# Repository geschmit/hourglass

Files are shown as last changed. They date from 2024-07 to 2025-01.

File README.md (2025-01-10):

# Hourglass
Hourglass is a custom PCB watch designed in KiCAD 7.0, to be funded by the Hack Club [OnBoard](https://github.com/hackclub/OnBoard/) grant, which allocates $100 for high schoolers to design and build their own custom PCBs.

## Features
- Accelerometer & Magnetometer for detecting orientation and movement
- 60 individual LEDs for displaying minutes & seconds
- RTC for high-precision timekeeping
- Programmable user buttons
- Revision A:
  - FIDO2 Authentication token
  - USB-C interface
- Revision B:
  - Cheap manufacturing cost

## Revisions
### [Revision A:](./hourglass_reva/) Working design iteration
> `Status: ✔️ (COMPLETE)`
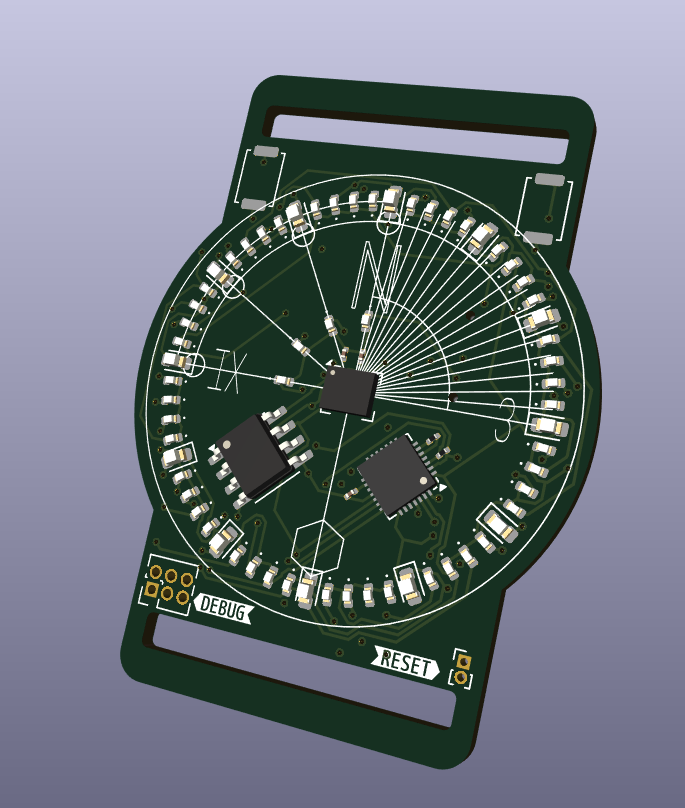
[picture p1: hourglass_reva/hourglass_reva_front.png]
reva front

Revision A is the original design, based on the Atmel ATMega32u4 microcontroller. It features a RTC and 9DoF magnetometer-accelerometer to detect orientation, magnetic field strength and more to act as both a device for keeping time and sense when the wearer has raised the watchface to observe. In addition, a USB-C port can allow for interfacing directly to the Mega for uploading code and other functions.

### [Revision B:](./hourglass_revb/) Cost-effective design
> `Status: ✔️ (COMPLETE)`
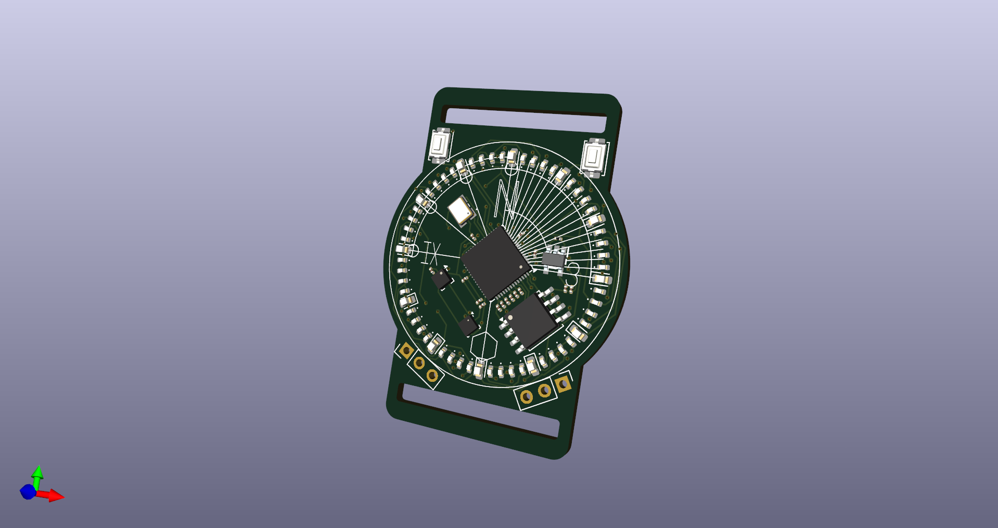
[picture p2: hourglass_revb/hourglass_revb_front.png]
revb front

Revision B is a easier, more affordable option. I'm working on this primarily because revision A is simply too expensive with all peripherals added in to have assembled via JLC's PCBA. It swaps the ATMega32 with an RP2040, the 9DoF magnetometer with split magnetometer & accelerometer ICs, and forgoes the rear battery slot alltogether. The caveat with this is you'll need to wire a battery to the device yourself, but comes at a tremendous discount with the requirement for dual-sided PCB assembly forgone.

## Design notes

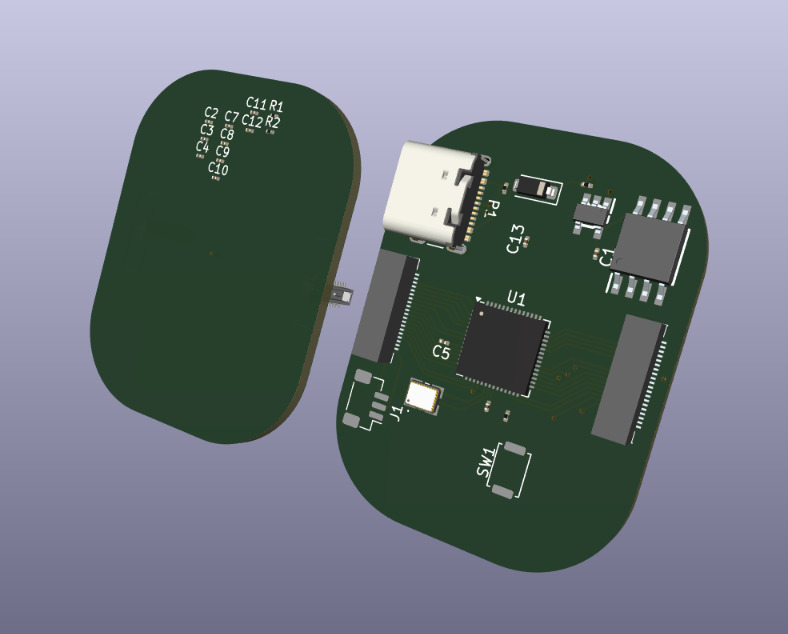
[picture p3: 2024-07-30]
hourglass_prototype/hourglass_prototype_front.png

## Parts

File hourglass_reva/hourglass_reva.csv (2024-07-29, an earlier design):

Id | Designator | Footprint | Quantity | Designation | Supplier and ref
1 | U1 | QFN-44-1EP_7x7mm_P0.5mm_EP5.2x5.2mm | 1 | ATmega32U4-M
2 | U2 | QFN-28-1EP_4x4mm_P0.4mm_EP2.3x2.3mm | 1 | IS31FL3731-QF

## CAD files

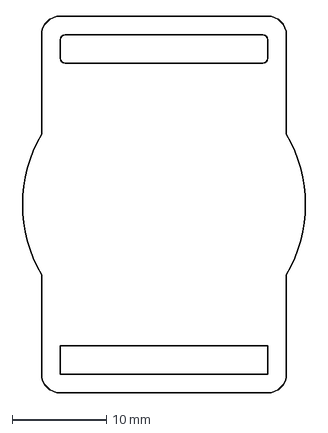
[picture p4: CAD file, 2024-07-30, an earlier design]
hourglass_reva/hourglass_base.dxf
31.3 x 40.0 mm

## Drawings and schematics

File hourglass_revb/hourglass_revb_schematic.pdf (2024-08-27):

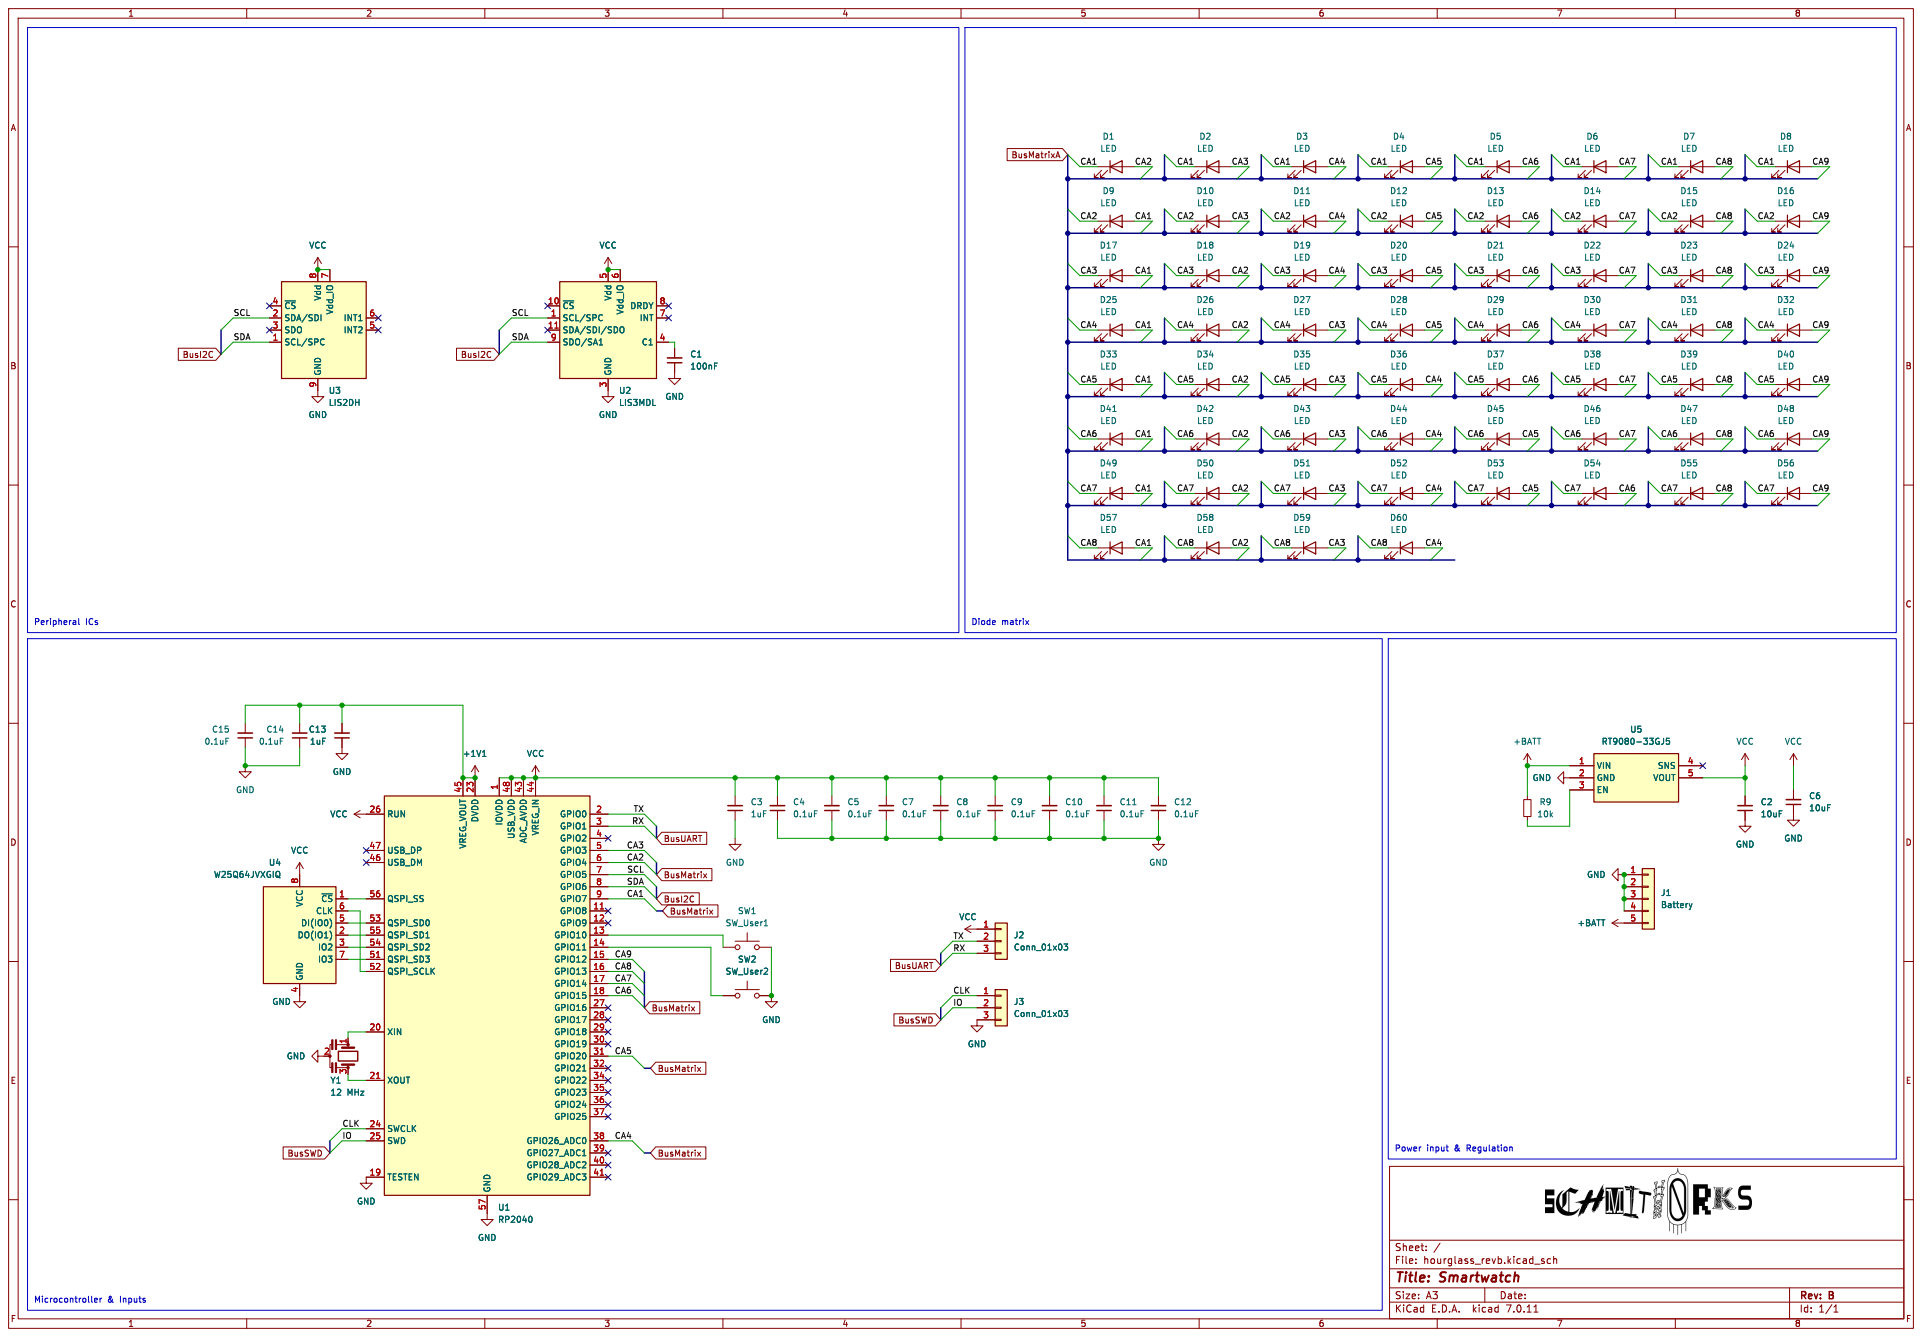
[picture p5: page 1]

SCL/SPC 1 SDA/SDI 2 SDO 3 ~{CS} 4

1 GPIO8 11 GPIO9 12 GPIO10 13 GPIO11 14 GPIO12 15 GPIO13 16 GPIO14 17 GPIO15 18 TESTEN 19 GPIO0 2 XIN 20 XOUT 21 DVDD 23 SWCLK 24 SWD 25 RUN 26 GPIO16 27 GPIO17 28 GPIO18 29 GPIO1 3 GPIO19 30 GPIO20 31 GPIO21 32 GPIO22 34 GPIO23 35 GPIO24 36 GPIO25 37 GPIO26_ADC0 38 GPIO27_ADC1 39 GPIO2 4 GPIO28_ADC2 40 GPIO29_ADC3 41 ADC_AVDD 43 VREG_IN 44 VREG_VOUT 45 USB_DM 46 USB_DP 47 USB_VDD 48 GPIO3 5 QSPI_SD3 51 QSPI_SCLK 52 QSPI_SD0 53 QSPI_SD2 54 QSPI_SD1 55 QSPI_SS 56 GND 57 GPIO4 6 GPIO5 7 GPIO6 8 GPIO7 9 VCC

1 GPIO8 11 GPIO9 12 GPIO10 13 GPIO11 14 GPIO12 15 GPIO13 16 GPIO14 17 GPIO15 18 TESTEN 19 GPIO0 2 XIN 20 XOUT 21 DVDD 23 SWCLK 24 SWD 25 RUN 26 GPIO16 27 GPIO17 28 GPIO18 29 GPIO1 3 GPIO19 30 GPIO20 31 GPIO21 32 GPIO22 34 GPIO23 35 GPIO24 36 GPIO25 37 GPIO26_ADC0 38 GPIO27_ADC1 39 GPIO2 4 GPIO28_ADC2 40 GPIO29_ADC3 41 ADC_AVDD 43 VREG_IN 44 VREG_VOUT 45 USB_DM 46 USB_DP 47 USB_VDD 48 GPIO3 5 QSPI_SD3 51 QSPI_SCLK 52 QSPI_SD0 53 QSPI_SD2 54 QSPI_SD1 55 QSPI_SS 56 GND 57 GPIO4 6 GPIO5 7 GPIO6 8 GPIO7 9 U1 RP2040 ~{CS}1 DO(IO1) 2

3 GND GND GND GND

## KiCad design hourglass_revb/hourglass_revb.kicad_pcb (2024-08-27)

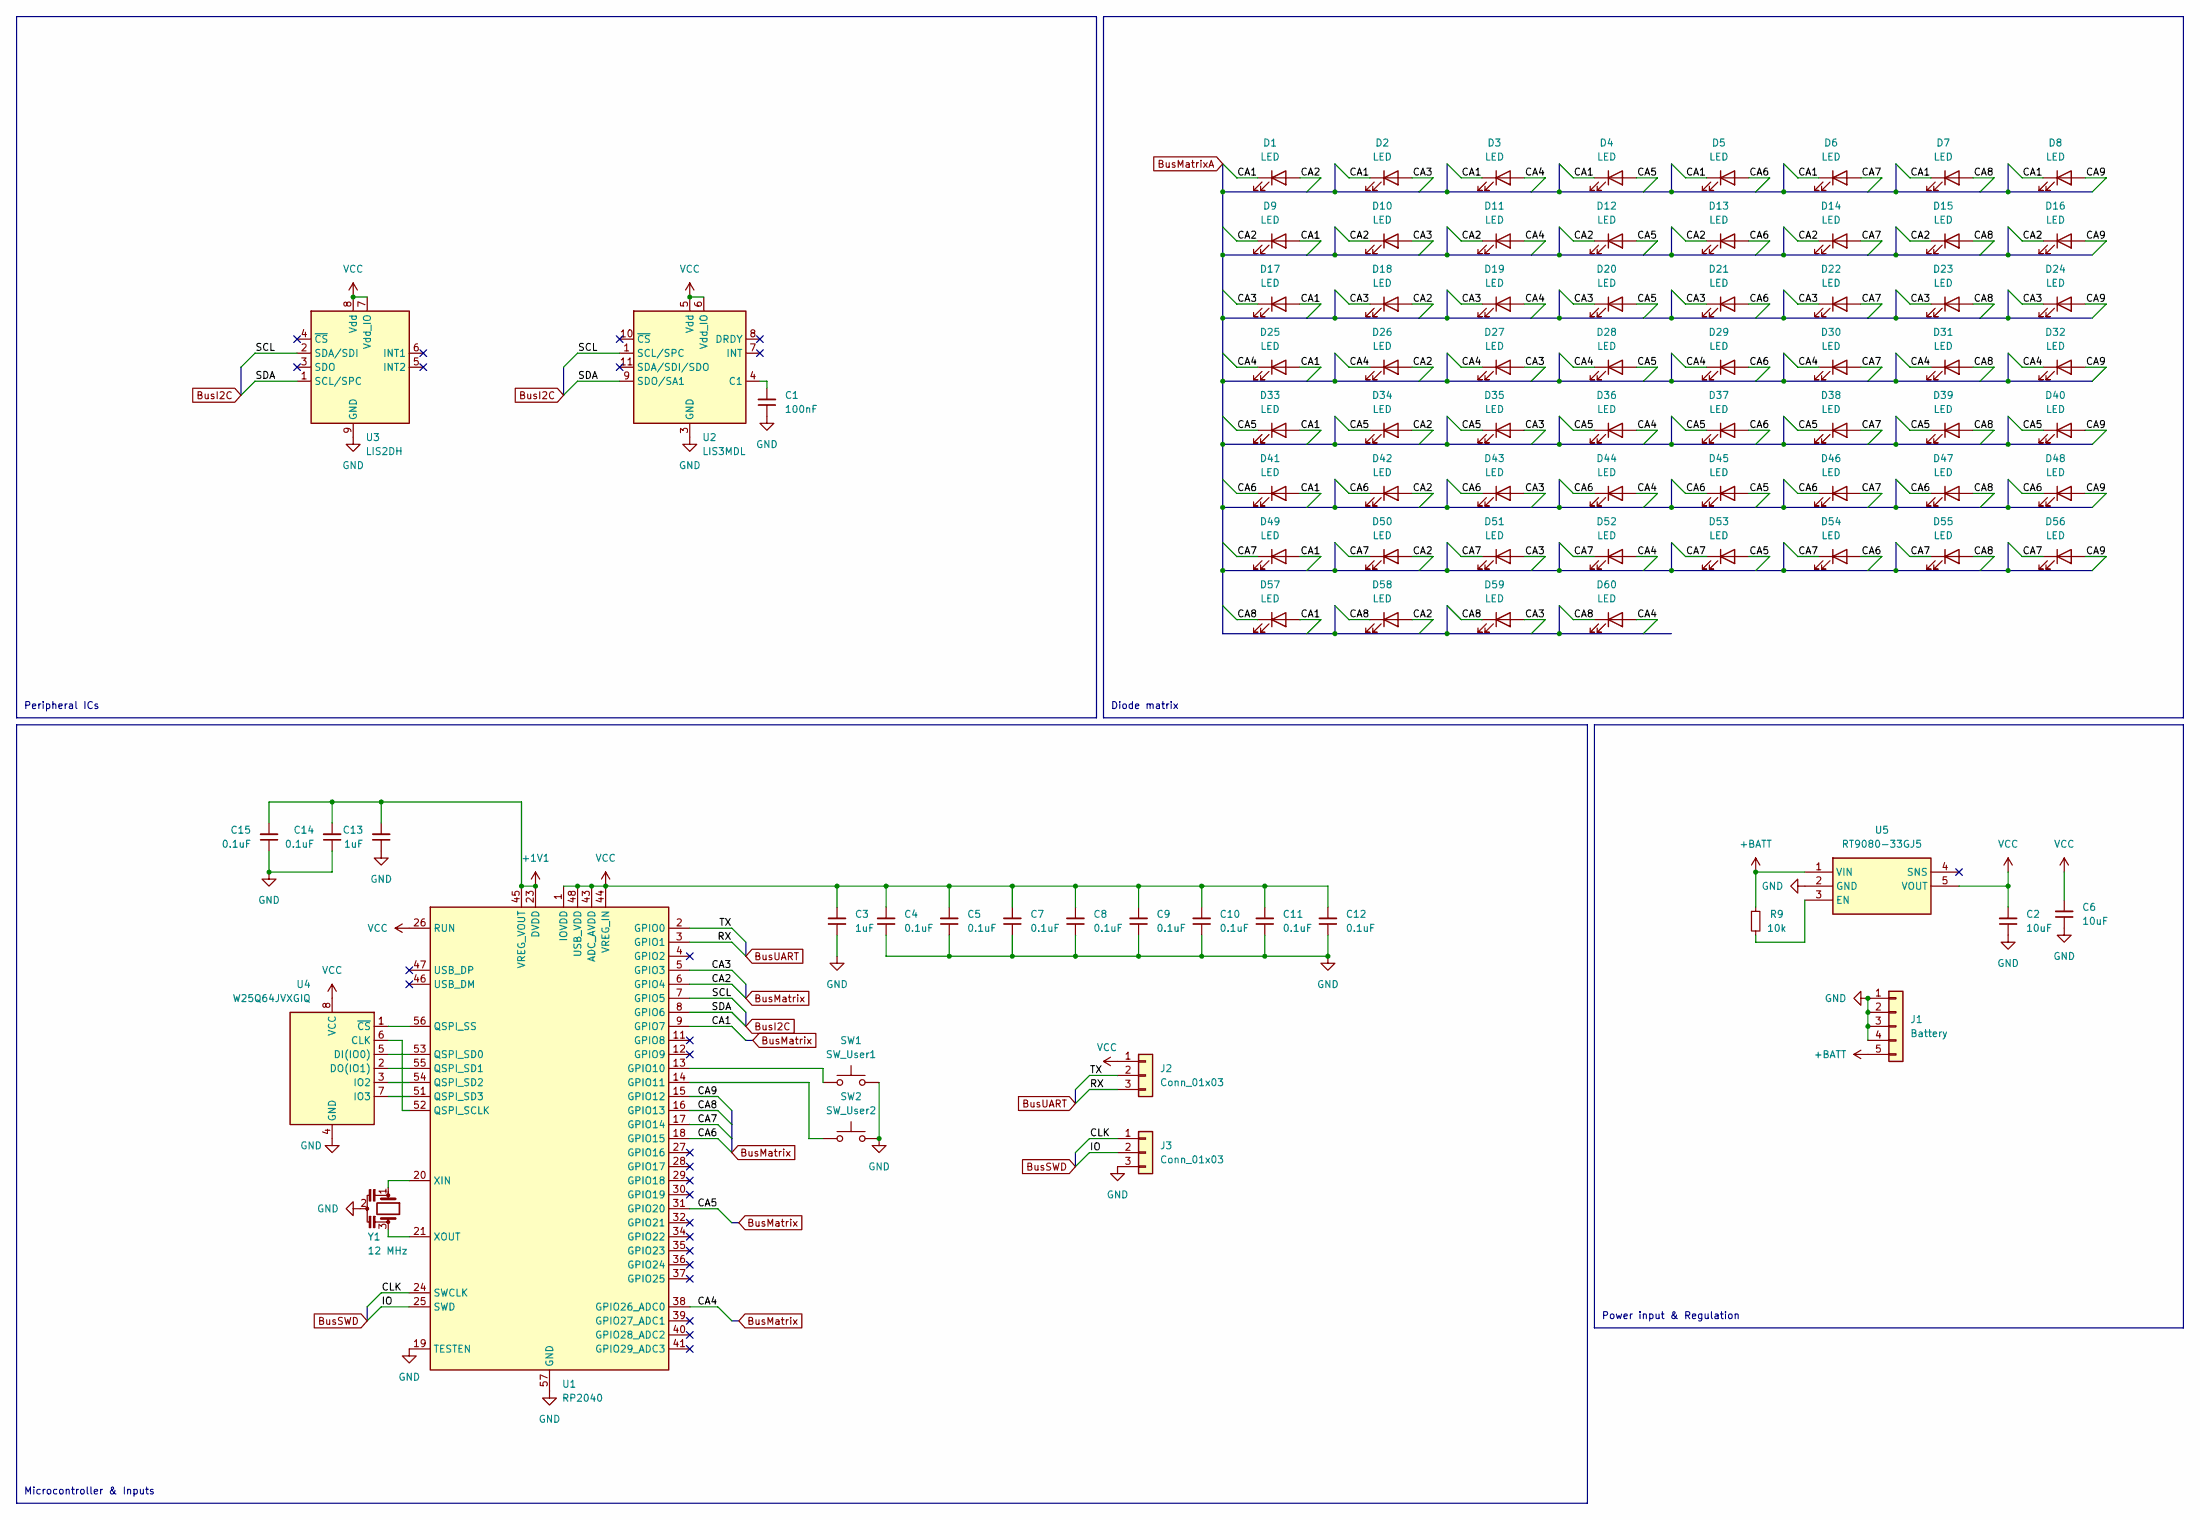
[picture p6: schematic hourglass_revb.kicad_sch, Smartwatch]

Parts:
C1: 100nF; C_0201_0603Metric
C2, C6: 10uF; C_0201_0603Metric
C3, C13: 1uF; C_0201_0603Metric
C4, C5, C7, C8, C9, C10, C11, C12, C14, C15: 0.1uF; C_0201_0603Metric
D1, D6, D11, D16, D21, D26, D31, D36, D41, D46, D51, D56: LED; LED_0603_1608Metric
D2, D3, D4, D5, D7, D8, D9, D10, D12, D13, D14, D15, D17, D18, D19, D20, D22, D23, D24, D25, D27, D28, D29, D30, D32, D33, D34, D35, D37, D38, D39, D40, D42, D43, D44, D45, D47, D48, D49, D50, D52, D53, D54, D55, D57, D58, D59, D60: LED; LED_0402_1005Metric
J1: Battery; BAT_BAT-HLD-001-THM
J2, J3: Conn_01x03; PinHeader_1x03_P2.54mm_Vertical
R9: 10k; R_0201_0603Metric
SW1: SW_User1; SW_Push_SPST_NO_Alps_SKRK
SW2: SW_User2; SW_Push_SPST_NO_Alps_SKRK
U1: RP2040; QFN-56-1EP_7x7mm_P0.4mm_EP3.2x3.2mm
U2: LIS3MDL; LGA-12_2x2mm_P0.5mm
U3: LIS2DH; LGA-14_2x2mm_P0.35mm_LayoutBorder3x4y
U4: W25Q64JVXGIQ; WSON-8-1EP_6x5mm_P1.27mm_EP3.4x4.3mm
U5: RT9080-33GJ5; SOT94P280X100-5N; Manufacturer_Part_Number RT9080-33GJ5; Mouser Part Number 835-RT9080-33GJ5
Y1: 12 MHz; ABM8272T3

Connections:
+1V1: C13.2, C14.2, C15.2, U1.23 (DVDD), U1.45 (VREG_VOUT), U1.50 (DVDD)
+BATT: J1.5, R9.1, U5.1 (VIN)
/CA1: D1.1 (K), D2.1 (K), D3.1 (K), D4.1 (K), D5.1 (K), D6.1 (K), D7.1 (K), D8.1 (K), D9.2 (A), D17.2 (A), D25.2 (A), D33.2 (A), D41.2 (A), D49.2 (A), D57.2 (A), U1.9 (GPIO7)
/CA2: D1.2 (A), D9.1 (K), D10.1 (K), D11.1 (K), D12.1 (K), D13.1 (K), D14.1 (K), D15.1 (K), D16.1 (K), D18.2 (A), D26.2 (A), D34.2 (A), D42.2 (A), D50.2 (A), D58.2 (A), U1.6 (GPIO4)
/CA3: D2.2 (A), D10.2 (A), D17.1 (K), D18.1 (K), D19.1 (K), D20.1 (K), D21.1 (K), D22.1 (K), D23.1 (K), D24.1 (K), D27.2 (A), D35.2 (A), D43.2 (A), D51.2 (A), D59.2 (A), U1.5 (GPIO3)
/CA4: D3.2 (A), D11.2 (A), D19.2 (A), D25.1 (K), D26.1 (K), D27.1 (K), D28.1 (K), D29.1 (K), D30.1 (K), D31.1 (K), D32.1 (K), D36.2 (A), D44.2 (A), D52.2 (A), D60.2 (A), U1.38 (GPIO26_ADC0)
/CA5: D4.2 (A), D12.2 (A), D20.2 (A), D28.2 (A), D33.1 (K), D34.1 (K), D35.1 (K), D36.1 (K), D37.1 (K), D38.1 (K), D39.1 (K), D40.1 (K), D45.2 (A), D53.2 (A), U1.31 (GPIO20)
/CA6: D5.2 (A), D13.2 (A), D21.2 (A), D29.2 (A), D37.2 (A), D41.1 (K), D42.1 (K), D43.1 (K), D44.1 (K), D45.1 (K), D46.1 (K), D47.1 (K), D48.1 (K), D54.2 (A), U1.18 (GPIO15)
/CA7: D6.2 (A), D14.2 (A), D22.2 (A), D30.2 (A), D38.2 (A), D46.2 (A), D49.1 (K), D50.1 (K), D51.1 (K), D52.1 (K), D53.1 (K), D54.1 (K), D55.1 (K), D56.1 (K), U1.17 (GPIO14)
/CA8: D7.2 (A), D15.2 (A), D23.2 (A), D31.2 (A), D39.2 (A), D47.2 (A), D55.2 (A), D57.1 (K), D58.1 (K), D59.1 (K), D60.1 (K), U1.16 (GPIO13)
/CA9: D8.2 (A), D16.2 (A), D24.2 (A), D32.2 (A), D40.2 (A), D48.2 (A), D56.2 (A), U1.15 (GPIO12)
/CLK: J3.1, U1.24 (SWCLK)
/IO: J3.2, U1.25 (SWD)
/RX: J2.3, U1.3 (GPIO1)
/SCL: U1.7 (GPIO5), U2.1 (SCL/SPC), U3.2 (SDA/SDI)
/SDA: U1.8 (GPIO6), U2.9 (SDO/SA1), U3.1 (SCL/SPC)
/TX: J2.2, U1.2 (GPIO0)
GND: C1.1, C2.1, C3.1, C4.1, C5.1, C6.1, C7.1, C8.1, C9.1, C10.1, C11.1, C12.1, C13.1, C14.1, C15.1, J1.1, J1.2, J1.3, J1.4, J3.3, SW1.2, SW2.2, U1.19 (TESTEN), U1.57 (GND), U2.2 (GND), U2.3 (GND), U2.12 (GND), U3.9 (GND), U3.10 (GND), U3.11 (GND), U3.12 (GND), U3.13 (GND), U3.14 (GND), U4.4 (GND), U5.2 (GND), Y1.2
unnamed: SW1.1, U1.13 (GPIO10)
unnamed: SW2.1, U1.14 (GPIO11)
unnamed: U1.52 (QSPI_SCLK), U4.6 (CLK)
unnamed: U1.53 (QSPI_SD0), U4.5 (DI(IO0))
unnamed: U1.55 (QSPI_SD1), U4.2 (DO(IO1))
unnamed: U1.54 (QSPI_SD2), U4.3 (IO2)
unnamed: U1.51 (QSPI_SD3), U4.7 (IO3)
unnamed: U1.56 (QSPI_SS), U4.1 (~CS)
unnamed: U1.20 (XIN), Y1.1
unnamed: U1.21 (XOUT), Y1.3
unnamed: C1.2, U2.4 (C1)
unnamed: R9.2, U5.3 (EN)
VCC: C2.2, C3.2, C4.2, C5.2, C6.2, C7.2, C8.2, C9.2, C10.2, C11.2, C12.2, J2.1, U1.1 (IOVDD), U1.10 (IOVDD), U1.22 (IOVDD), U1.26 (RUN), U1.33 (IOVDD), U1.42 (IOVDD), U1.43 (ADC_AVDD), U1.44 (VREG_IN), U1.48 (USB_VDD), U1.49 (IOVDD), U2.5 (Vdd), U2.6 (Vdd_IO), U3.7 (Vdd_IO), U3.8 (Vdd), U4.8 (VCC), U5.5 (VOUT)

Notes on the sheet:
Power input & Regulation
Diode matrix
Peripheral ICs
Microcontroller & Inputs

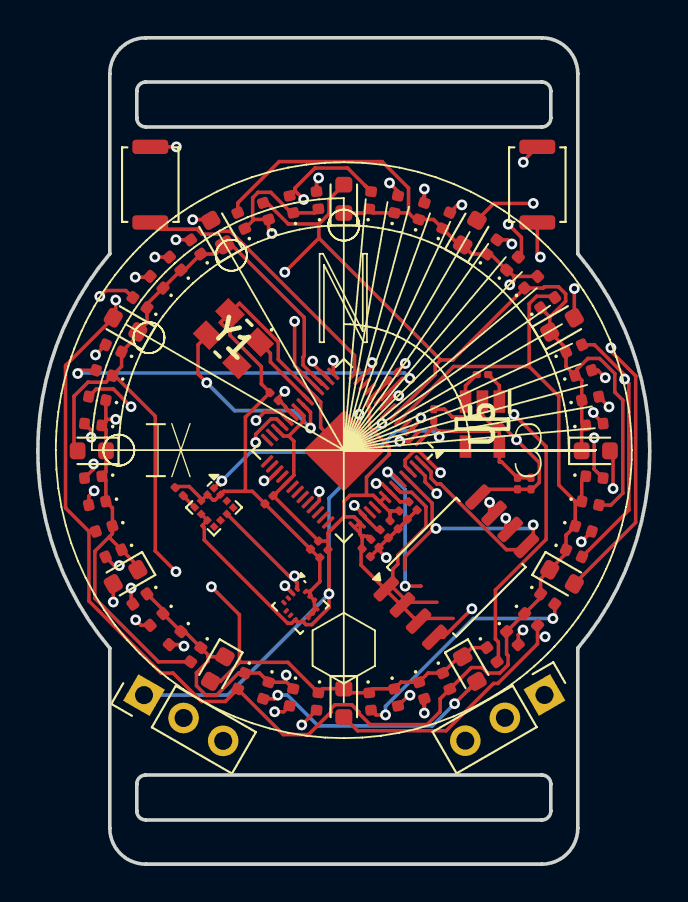
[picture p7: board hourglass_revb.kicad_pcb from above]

Board: 4 copper layers, 34.0 x 45.9 mm, 87 parts (1 on the bottom side), 31 nets.

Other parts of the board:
kibuzzard-66C6528B: G***; kibuzzard-66C6528B

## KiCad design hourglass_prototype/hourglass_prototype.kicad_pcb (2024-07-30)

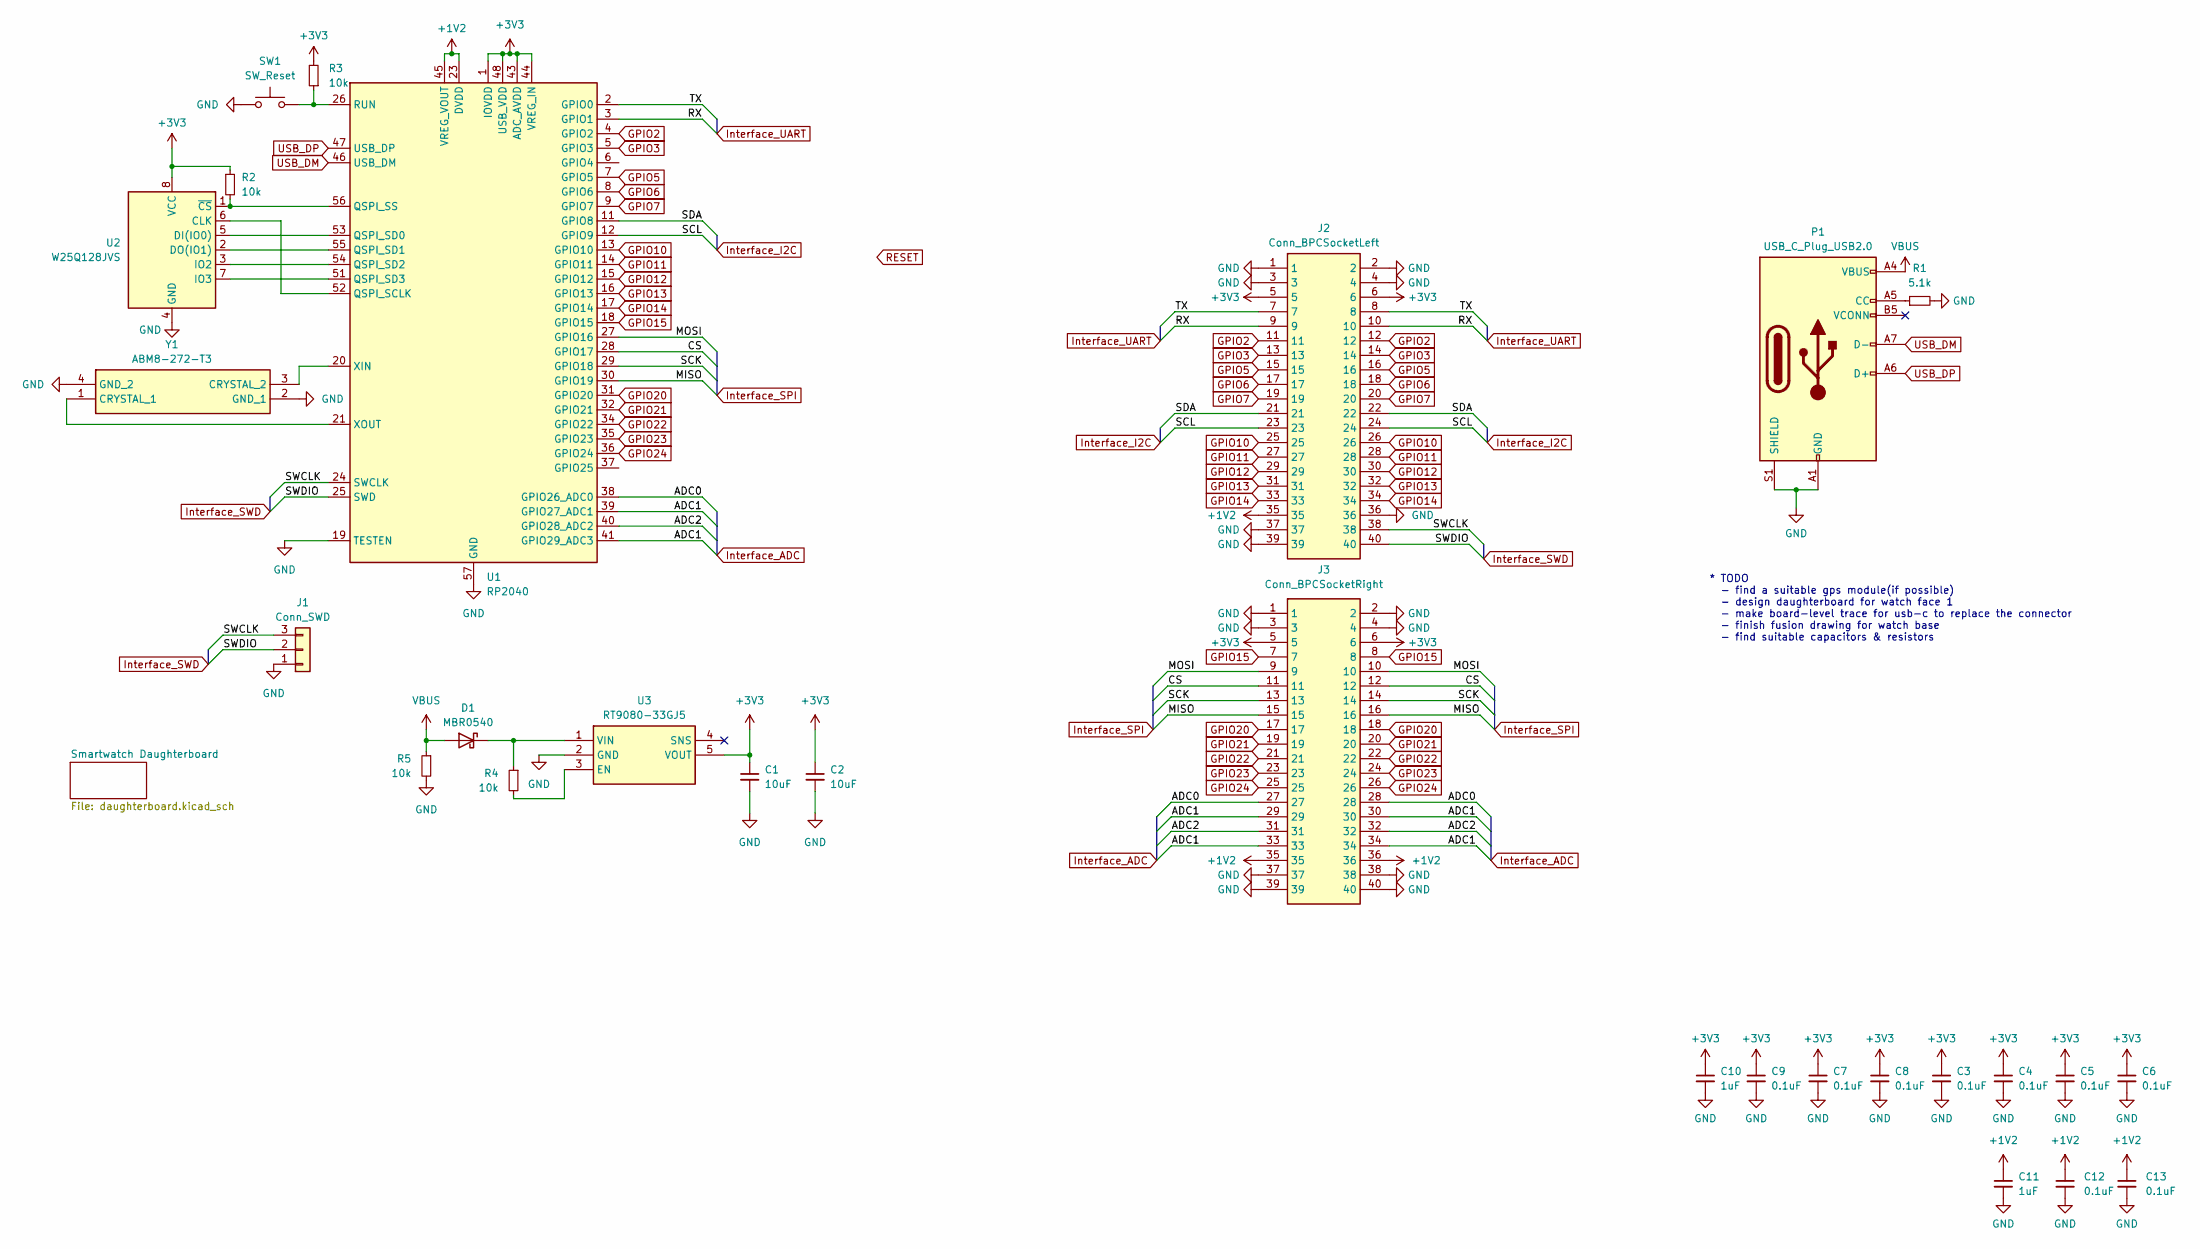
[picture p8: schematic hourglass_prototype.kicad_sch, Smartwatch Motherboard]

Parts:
C1, C2: 10uF; C_0201_0603Metric
C3, C4, C5, C6, C7, C8, C9, C12, C13: 0.1uF; C_0201_0603Metric
C10, C11: 1uF; C_0201_0603Metric
D1: MBR0540; D_SOD-123
J1: Conn_SWD; JST_SH_BM03B-SRSS-TB_1x03-1MP_P1.00mm_Vertical
J2: Conn_BPCSocketLeft; DF40HC3040DS04V51; Manufacturer_Part_Number DF40HC(3.0)-40DS-0.4V(51); Mouser Part Number 798-DF40HC3040DS04V5
J3: Conn_BPCSocketRight; DF40HC3040DS04V51; Manufacturer_Part_Number DF40HC(3.0)-40DS-0.4V(51); Mouser Part Number 798-DF40HC3040DS04V5
P1: USB_C_Plug_USB2.0; USB_C_Receptacle_GCT_USB4105-xx-A_16P_TopMnt_Horizontal
R1: 5.1k; R_0201_0603Metric
R2, R3, R4, R5: 10k; R_0201_0603Metric
SW1: SW_Reset
U1: RP2040; QFN-56-1EP_7x7mm_P0.4mm_EP3.2x3.2mm
U2: W25Q128JVS; SOIC127P790X216-8N
U3: RT9080-33GJ5; SOT94P280X100-5N; Manufacturer_Part_Number RT9080-33GJ5; Mouser Part Number 835-RT9080-33GJ5
Y1: ABM8-272-T3; ABM8272T3; Manufacturer_Part_Number ABM8-272-T3; Mouser Part Number 815-ABM8-272-T3

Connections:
+3V3: C1.1, C2.1, C3.1, C4.1, C5.1, C6.1, C7.1, C8.1, C9.1, C10.1, J2.5, J2.6, J3.5, J3.6, R2.1, R3.2, U1.1 (IOVDD), U1.10 (IOVDD), U1.22 (IOVDD), U1.33 (IOVDD), U1.42 (IOVDD), U1.43 (ADC_AVDD), U1.44 (VREG_IN), U1.48 (USB_VDD), U1.49 (IOVDD), U2.8 (VCC), U3.5 (VOUT); also elsewhere on the board
/ADC0: J3.27, J3.28, U1.38 (GPIO26_ADC0)
/ADC2: J3.31, J3.32, U1.40 (GPIO28_ADC2)
/CS: J3.11, J3.12, U1.28 (GPIO17)
/MISO: J3.15, J3.16, U1.30 (GPIO19)
/MOSI: J3.9, J3.10, U1.27 (GPIO16)
/RX: J2.9, J2.10, U1.3 (GPIO1)
/SCK: J3.13, J3.14, U1.29 (GPIO18)
/SCL: J2.23, J2.24, U1.12 (GPIO9)
/SDA: J2.21, J2.22, U1.11 (GPIO8)
/SWCLK: J1.3, J2.38, U1.24 (SWCLK)
/SWDIO: J1.2, J2.40, U1.25 (SWD)
/TX: J2.7, J2.8, U1.2 (GPIO0)
GPIO2: J2.11, J2.12, U1.4 (GPIO2); also elsewhere on the board
GPIO3: J2.13, J2.14, U1.5 (GPIO3); also elsewhere on the board
GPIO5: J2.15, J2.16, U1.7 (GPIO5); also elsewhere on the board
GPIO6: J2.17, J2.18, U1.8 (GPIO6); also elsewhere on the board
GPIO7: J2.19, J2.20, U1.9 (GPIO7); also elsewhere on the board
GPIO10: J2.25, J2.26, U1.13 (GPIO10); also elsewhere on the board
GPIO11: J2.27, J2.28, U1.14 (GPIO11); also elsewhere on the board
GPIO12: J2.29, J2.30, U1.15 (GPIO12); also elsewhere on the board
GPIO13: J2.31, J2.32, U1.16 (GPIO13); also elsewhere on the board
GPIO14: J2.33, J2.34, U1.17 (GPIO14); also elsewhere on the board
GPIO15: J3.7, J3.8, U1.18 (GPIO15); also elsewhere on the board
GPIO20: J3.17, J3.18, U1.31 (GPIO20); also elsewhere on the board
GPIO21: J3.19, J3.20, U1.32 (GPIO21); also elsewhere on the board
GPIO22: J3.21, J3.22, U1.34 (GPIO22); also elsewhere on the board
GPIO23: J3.23, J3.24, U1.35 (GPIO23); also elsewhere on the board
GPIO24: J3.25, J3.26, U1.36 (GPIO24); also elsewhere on the board
unnamed: D1.1 (K), R4.1, U3.1 (VIN)
unnamed: P1.A5 (CC), R1.1
unnamed: U1.52 (QSPI_SCLK), U2.6 (CLK)
unnamed: U1.53 (QSPI_SD0), U2.5 (DI(IO0))
unnamed: U1.55 (QSPI_SD1), U2.2 (DO(IO1))
unnamed: U1.54 (QSPI_SD2), U2.3 (IO2)
unnamed: U1.51 (QSPI_SD3), U2.7 (IO3)
unnamed: R2.2, U1.56 (QSPI_SS), U2.1 (~CS)
unnamed: R3.1, SW1.2, U1.26 (RUN)
unnamed: U1.20 (XIN), Y1.3 (CRYSTAL_2)
unnamed: U1.21 (XOUT), Y1.1 (CRYSTAL_1)
unnamed: R4.2, U3.3 (EN)
USB_DM: P1.A7 (D-), U1.46 (USB_DM)
USB_DP: P1.A6 (D+), U1.47 (USB_DP)
VBUS: D1.2 (A), P1.A4 (VBUS), P1.A9 (VBUS), P1.B4 (VBUS), P1.B9 (VBUS), R5.1

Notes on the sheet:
* TODO - find a suitable gps module(if possible) - design daughterboard for watch face 1 - make board-level trace for usb-c to replace the connector - finish fusion drawing for watch base - find suitable capacitors & resistors

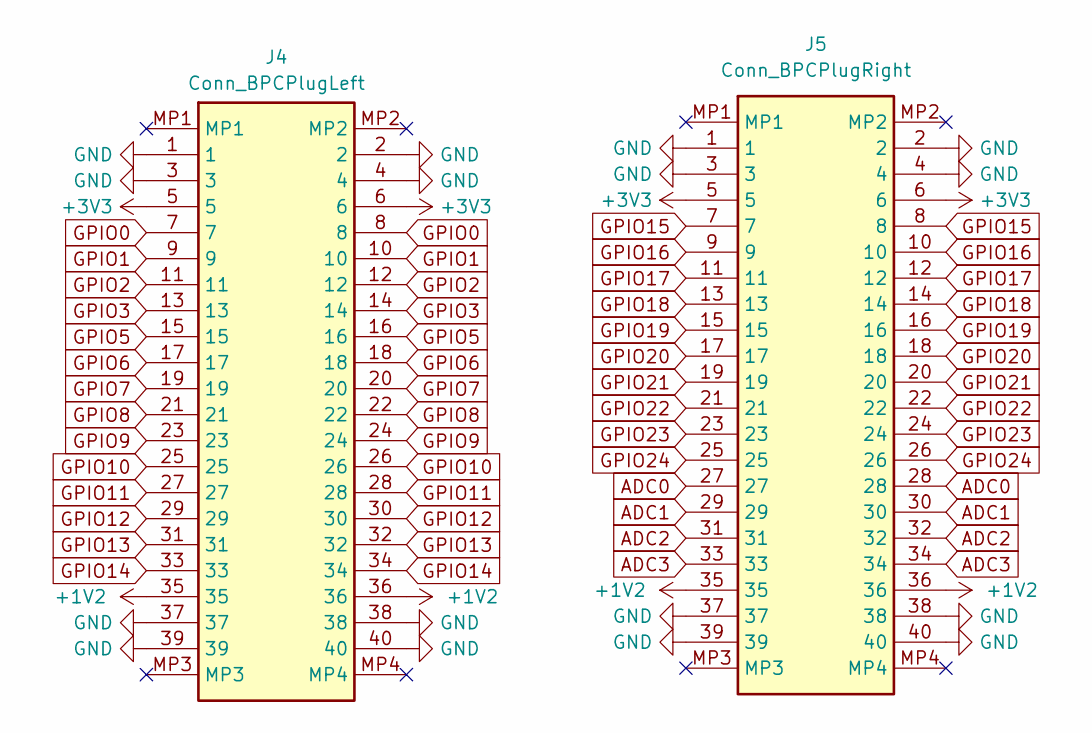
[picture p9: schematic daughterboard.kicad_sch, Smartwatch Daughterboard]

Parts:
J4: Conn_BPCPlugLeft; DF40C40DP04V51; Manufacturer_Part_Number DF40C-40DP-0.4V(51); Mouser Part Number 798-DF40C40DP0.4V51
J5: Conn_BPCPlugRight; DF40C40DP04V51; Manufacturer_Part_Number DF40C-40DP-0.4V(51); Mouser Part Number 798-DF40C40DP0.4V51

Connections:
+3V3: J4.5, J4.6, J5.5, J5.6; also elsewhere on the board
ADC0: J5.27, J5.28
ADC1: J5.29, J5.30
ADC2: J5.31, J5.32
ADC3: J5.33, J5.34
GPIO0: J4.7, J4.8
GPIO1: J4.9, J4.10
GPIO2: J4.11, J4.12; also elsewhere on the board
GPIO3: J4.13, J4.14; also elsewhere on the board
GPIO5: J4.15, J4.16; also elsewhere on the board
GPIO6: J4.17, J4.18; also elsewhere on the board
GPIO7: J4.19, J4.20; also elsewhere on the board
GPIO8: J4.21, J4.22
GPIO9: J4.23, J4.24
GPIO10: J4.25, J4.26; also elsewhere on the board
GPIO11: J4.27, J4.28; also elsewhere on the board
GPIO12: J4.29, J4.30; also elsewhere on the board
GPIO13: J4.31, J4.32; also elsewhere on the board
GPIO14: J4.33, J4.34; also elsewhere on the board
GPIO15: J5.7, J5.8; also elsewhere on the board
GPIO16: J5.9, J5.10
GPIO17: J5.11, J5.12
GPIO18: J5.13, J5.14
GPIO19: J5.15, J5.16
GPIO20: J5.17, J5.18; also elsewhere on the board
GPIO21: J5.19, J5.20; also elsewhere on the board
GPIO22: J5.21, J5.22; also elsewhere on the board
GPIO23: J5.23, J5.24; also elsewhere on the board
GPIO24: J5.25, J5.26; also elsewhere on the board

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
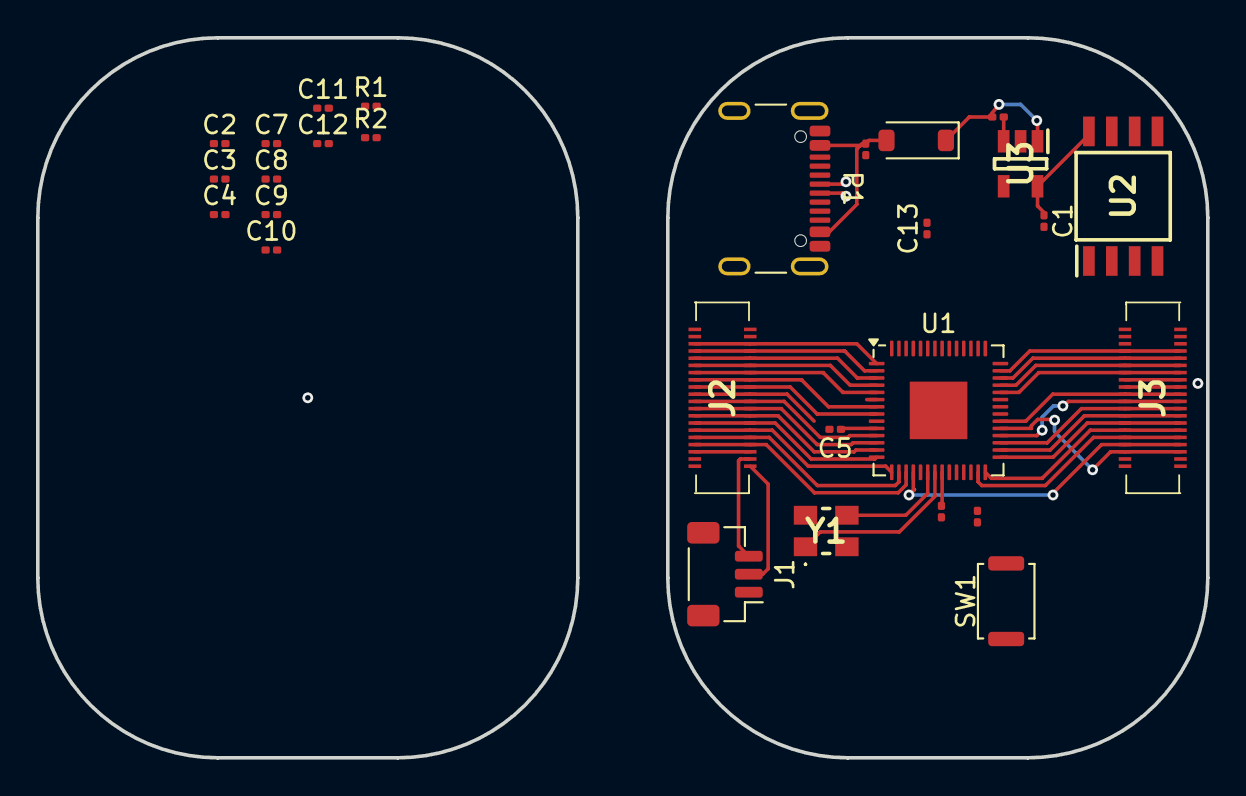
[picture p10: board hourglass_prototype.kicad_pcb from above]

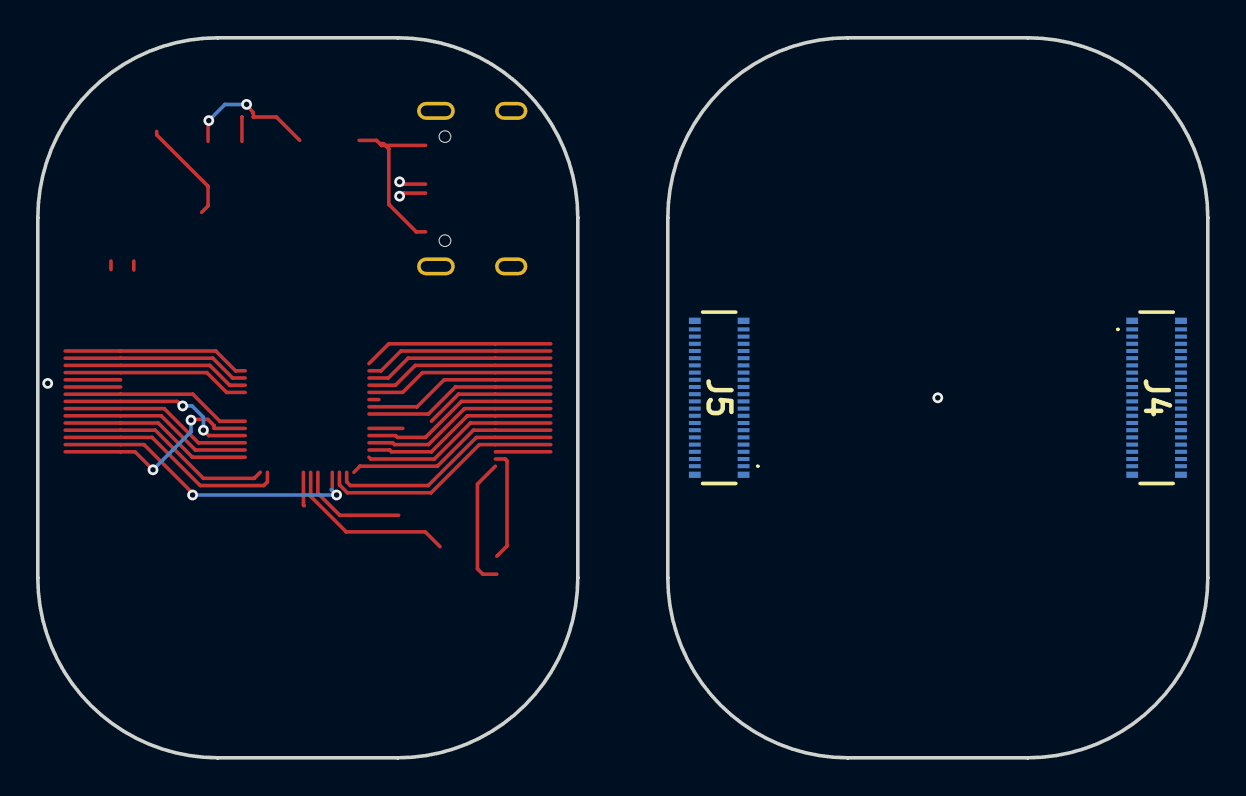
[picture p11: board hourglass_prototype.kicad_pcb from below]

Board: 2 copper layers, 65.0 x 40.0 mm, 30 parts (2 on the bottom side), 60 nets.

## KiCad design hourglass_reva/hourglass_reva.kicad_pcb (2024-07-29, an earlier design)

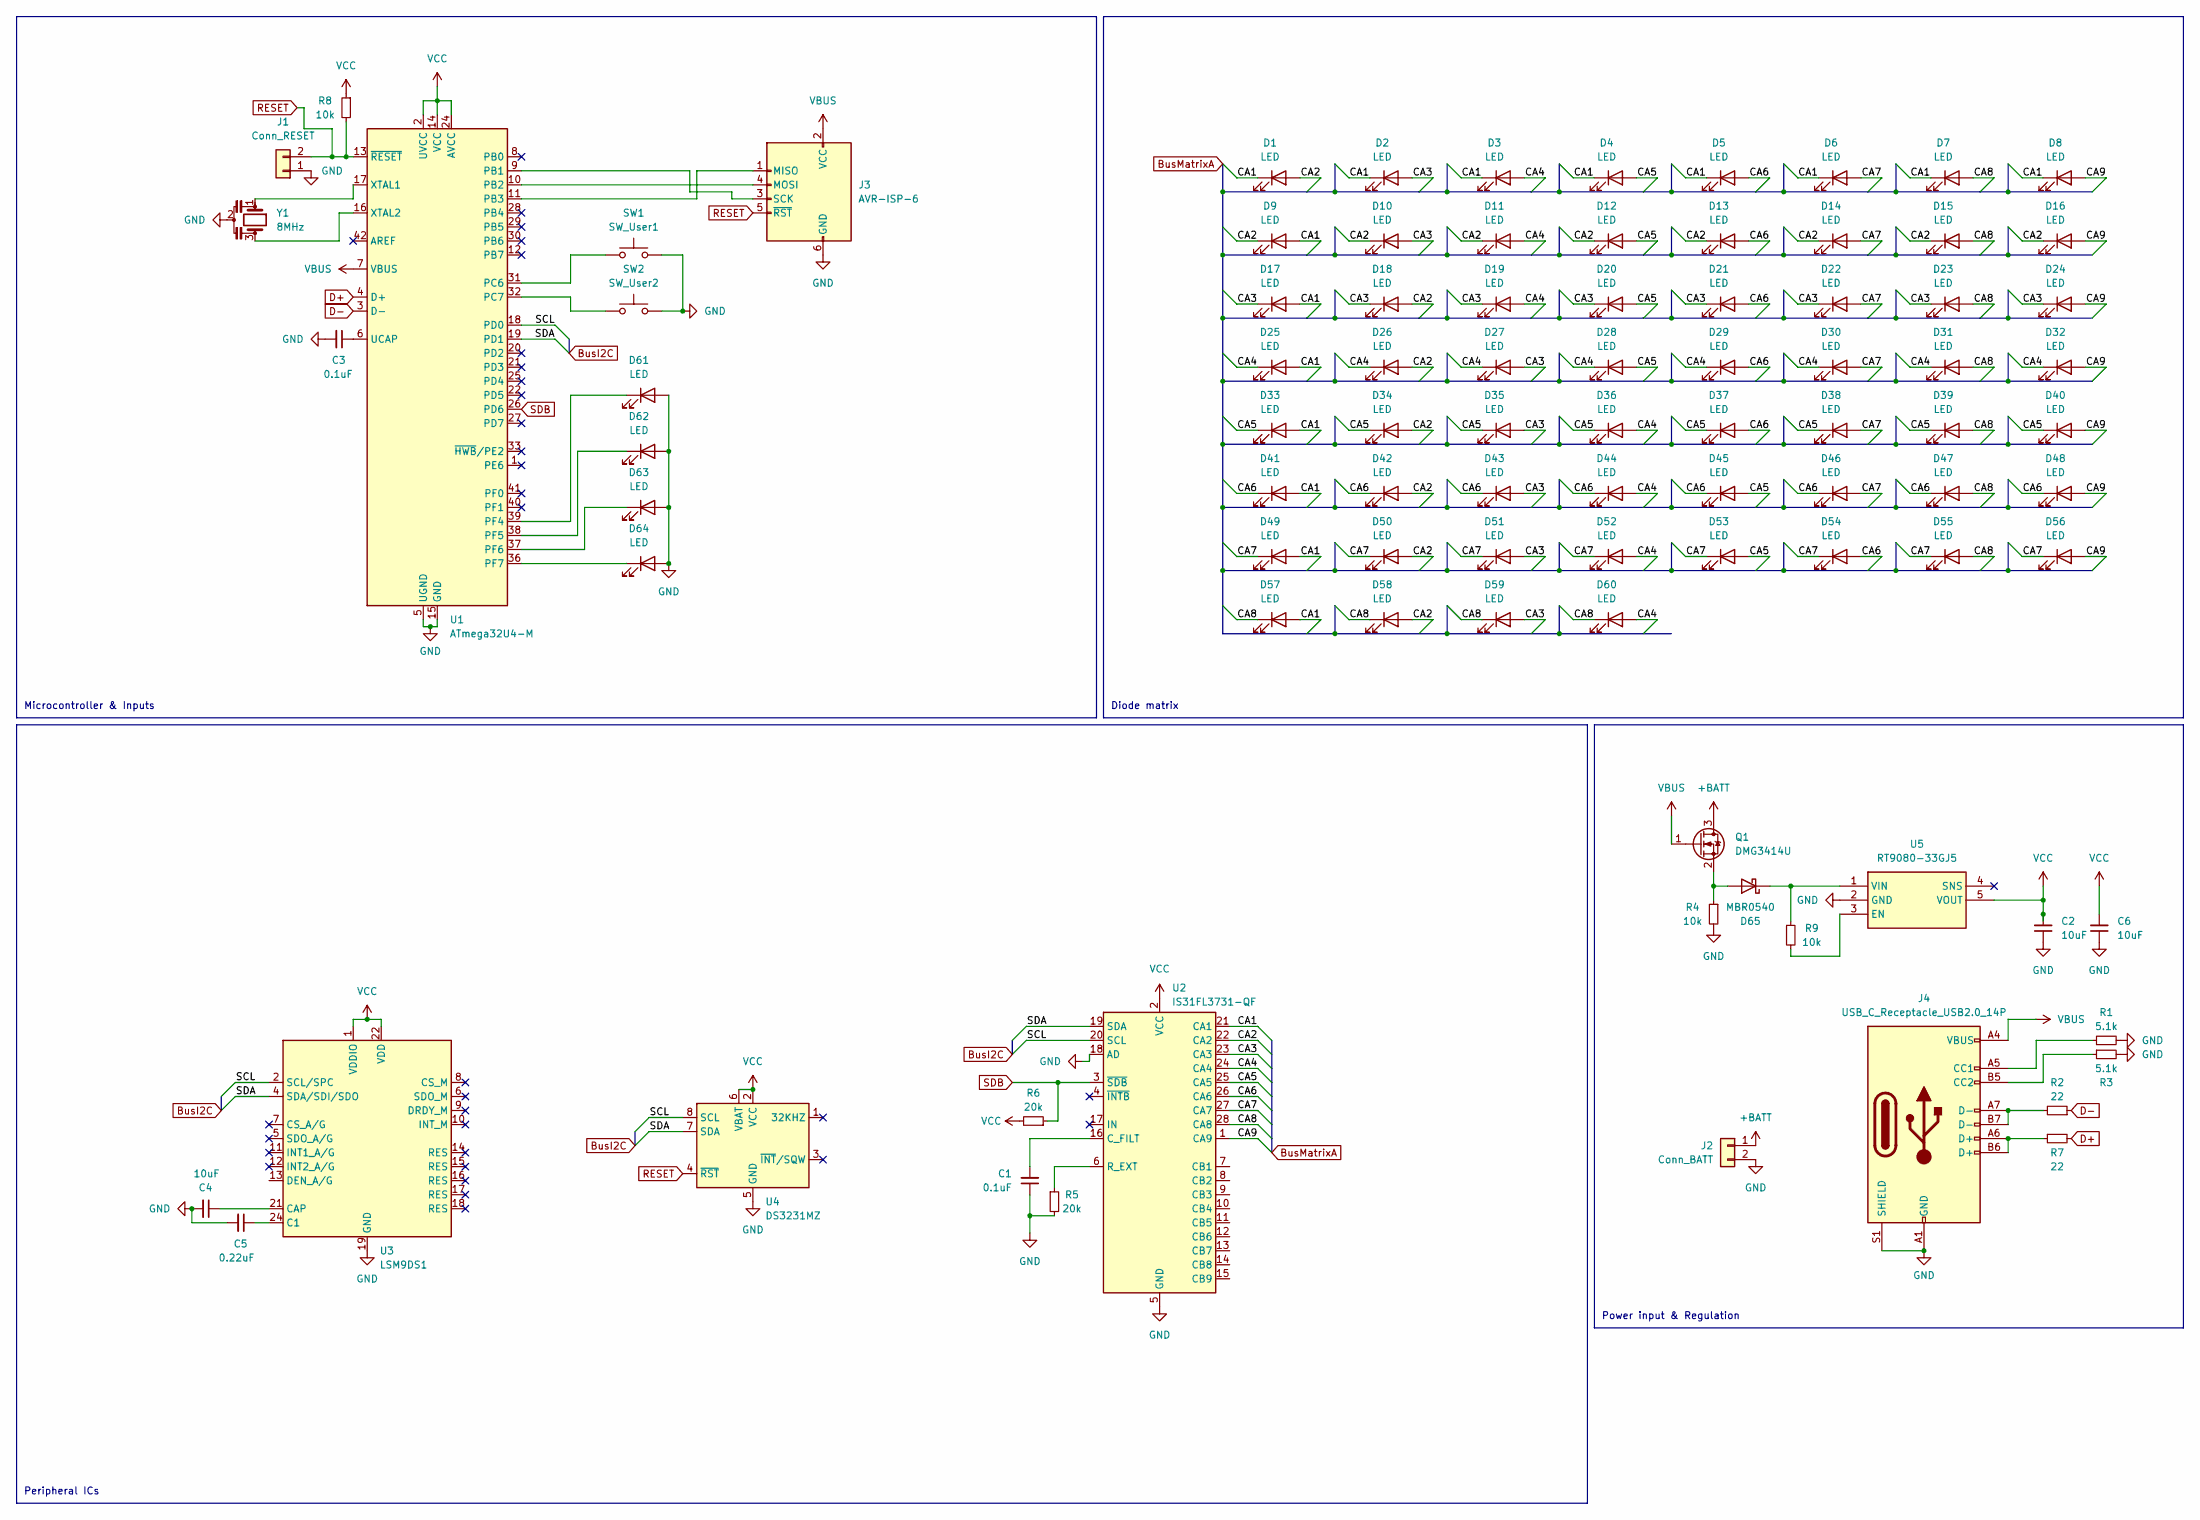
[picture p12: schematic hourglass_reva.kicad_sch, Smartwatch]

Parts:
C1, C3: 0.1uF; C_0201_0603Metric
C2, C4, C6: 10uF; C_0201_0603Metric
C5: 0.22uF; C_0201_0603Metric
D1, D6, D11, D16, D21, D26, D31, D36, D41, D46, D51, D56: LED; LED_0603_1608Metric
D2, D3, D4, D5, D7, D8, D9, D10, D12, D13, D14, D15, D17, D18, D19, D20, D22, D23, D24, D25, D27, D28, D29, D30, D32, D33, D34, D35, D37, D38, D39, D40, D42, D43, D44, D45, D47, D48, D49, D50, D52, D53, D54, D55, D57, D58, D59, D60, D61, D62, D63, D64: LED; LED_0402_1005Metric
D65: MBR0540; D_SOD-123
J1: Conn_RESET; PinHeader_1x02_P1.00mm_Vertical
J2: Conn_BATT; BatteryHolder_LINX_BAT-HLD-012-SMT
J3: AVR-ISP-6; PinHeader_2x03_P1.27mm_Vertical
J4: USB_C_Receptacle_USB2.0_14P; USB_C_Receptacle_GCT_USB4110
Q1: DMG3414U; SOT-23
R1, R3: 5.1k; R_0201_0603Metric
R2, R7: 22; R_0201_0603Metric
R4, R8, R9: 10k; R_0201_0603Metric
R5, R6: 20k; R_0201_0603Metric
SW1: SW_User1; SW_Push_SPST_NO_Alps_SKRK
SW2: SW_User2; SW_Push_SPST_NO_Alps_SKRK
U1: ATmega32U4-M; QFN-44-1EP_7x7mm_P0.5mm_EP5.2x5.2mm
U2: IS31FL3731-QF; QFN-28-1EP_4x4mm_P0.4mm_EP2.3x2.3mm
U3: LSM9DS1; LGA-24L_3x3.5mm_P0.43mm
U4: DS3231MZ; SOIC-8_3.9x4.9mm_P1.27mm
U5: RT9080-33GJ5; SOT94P280X100-5N; Manufacturer_Part_Number RT9080-33GJ5; Mouser Part Number 835-RT9080-33GJ5
Y1: 8MHz; Crystal_SMD_3225-4Pin_3.2x2.5mm

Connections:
+BATT: J2.1, Q1.3 (D)
/CA1: D1.1 (K), D2.1 (K), D3.1 (K), D4.1 (K), D5.1 (K), D6.1 (K), D7.1 (K), D8.1 (K), D9.2 (A), D17.2 (A), D25.2 (A), D33.2 (A), D41.2 (A), D49.2 (A), D57.2 (A), U2.21 (CA1)
/CA2: D1.2 (A), D9.1 (K), D10.1 (K), D11.1 (K), D12.1 (K), D13.1 (K), D14.1 (K), D15.1 (K), D16.1 (K), D18.2 (A), D26.2 (A), D34.2 (A), D42.2 (A), D50.2 (A), D58.2 (A), U2.22 (CA2)
/CA3: D2.2 (A), D10.2 (A), D17.1 (K), D18.1 (K), D19.1 (K), D20.1 (K), D21.1 (K), D22.1 (K), D23.1 (K), D24.1 (K), D27.2 (A), D35.2 (A), D43.2 (A), D51.2 (A), D59.2 (A), U2.23 (CA3)
/CA4: D3.2 (A), D11.2 (A), D19.2 (A), D25.1 (K), D26.1 (K), D27.1 (K), D28.1 (K), D29.1 (K), D30.1 (K), D31.1 (K), D32.1 (K), D36.2 (A), D44.2 (A), D52.2 (A), D60.2 (A), U2.24 (CA4)
/CA5: D4.2 (A), D12.2 (A), D20.2 (A), D28.2 (A), D33.1 (K), D34.1 (K), D35.1 (K), D36.1 (K), D37.1 (K), D38.1 (K), D39.1 (K), D40.1 (K), D45.2 (A), D53.2 (A), U2.25 (CA5)
/CA6: D5.2 (A), D13.2 (A), D21.2 (A), D29.2 (A), D37.2 (A), D41.1 (K), D42.1 (K), D43.1 (K), D44.1 (K), D45.1 (K), D46.1 (K), D47.1 (K), D48.1 (K), D54.2 (A), U2.26 (CA6)
/CA7: D6.2 (A), D14.2 (A), D22.2 (A), D30.2 (A), D38.2 (A), D46.2 (A), D49.1 (K), D50.1 (K), D51.1 (K), D52.1 (K), D53.1 (K), D54.1 (K), D55.1 (K), D56.1 (K), U2.27 (CA7)
/CA8: D7.2 (A), D15.2 (A), D23.2 (A), D31.2 (A), D39.2 (A), D47.2 (A), D55.2 (A), D57.1 (K), D58.1 (K), D59.1 (K), D60.1 (K), U2.28 (CA8)
/CA9: D8.2 (A), D16.2 (A), D24.2 (A), D32.2 (A), D40.2 (A), D48.2 (A), D56.2 (A), U2.1 (CA9)
/SCL: U1.18 (PD0), U2.20 (SCL), U3.2 (SCL/SPC), U4.8 (SCL)
/SDA: U1.19 (PD1), U2.19 (SDA), U3.4 (SDA/SDI/SDO), U4.7 (SDA)
D+: R7.2, U1.4 (D+)
D-: R2.1, U1.3 (D-)
GND: C1.1, C2.1, C3.2, C4.2, C5.2, C6.1, D61.2 (A), D62.2 (A), D63.2 (A), D64.2 (A), J1.1, J2.2, J3.6 (GND), J4.A1 (GND), J4.A12 (GND), J4.B1 (GND), J4.B12 (GND), J4.S1 (SHIELD), R1.2, R3.2, R4.2, R5.2, SW1.2, SW2.2, U1.5 (UGND), U1.15 (GND), U1.23 (GND), U1.35 (GND), U1.43 (GND), U1.45 (GND), U2.5 (GND), U2.18 (AD), U2.29 (GND), U3.19 (GND), U3.20 (GND), U4.5 (GND), U5.2 (GND), Y1.2
unnamed: D61.1 (K), U1.39 (PF4)
unnamed: D62.1 (K), U1.38 (PF5)
unnamed: D63.1 (K), U1.37 (PF6)
unnamed: D64.1 (K), U1.36 (PF7)
unnamed: D65.2 (A), Q1.2 (S), R4.1
unnamed: D65.1 (K), R9.1, U5.1 (VIN)
unnamed: J3.1 (MISO), U1.11 (PB3)
unnamed: J3.4 (MOSI), U1.10 (PB2)
unnamed: J3.3 (SCK), U1.9 (PB1)
unnamed: J4.A5 (CC1), R1.1
unnamed: J4.B5 (CC2), R3.1
unnamed: J4.A6 (D+), J4.B6 (D+), R7.1
unnamed: J4.A7 (D-), J4.B7 (D-), R2.2
unnamed: SW1.1, U1.31 (PC6)
unnamed: SW2.1, U1.32 (PC7)
unnamed: C3.1, U1.6 (UCAP)
unnamed: U1.17 (XTAL1), Y1.1
unnamed: U1.16 (XTAL2), Y1.3
unnamed: C1.2, U2.16 (C_FILT)
unnamed: R5.1, U2.6 (R_EXT)
unnamed: C5.1, U3.24 (C1)
unnamed: C4.1, U3.21 (CAP)
unnamed: R9.2, U5.3 (EN)
RESET: J1.2, J3.5 (~RST), R8.2, U1.13 (~RESET), U4.4 (~RST)
SDB: R6.1, U1.26 (PD6), U2.3 (~SDB)
VBUS: J3.2 (VCC), J4.A4 (VBUS), J4.A9 (VBUS), J4.B4 (VBUS), J4.B9 (VBUS), Q1.1 (G), U1.7 (VBUS)
VCC: C2.2, C6.2, R6.2, R8.1, U1.2 (UVCC), U1.14 (VCC), U1.24 (AVCC), U1.34 (VCC), U1.44 (AVCC), U2.2 (VCC), U3.1 (VDDIO), U3.3 (VDDIO), U3.22 (VDD), U3.23 (VDD), U4.2 (VCC), U4.6 (VBAT), U5.5 (VOUT)

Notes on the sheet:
Power input & Regulation
Diode matrix
Peripheral ICs
Microcontroller & Inputs

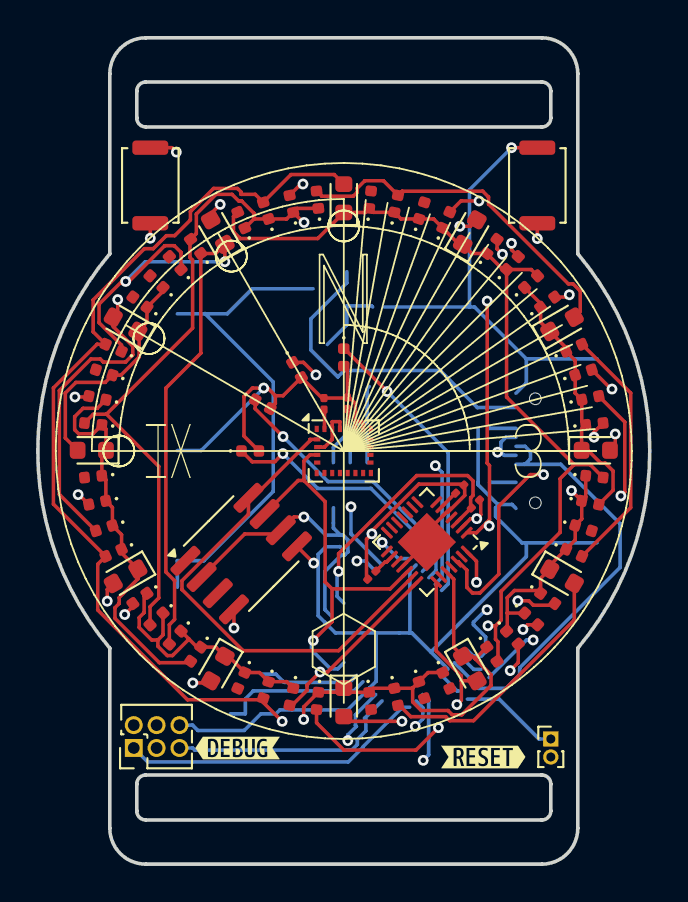
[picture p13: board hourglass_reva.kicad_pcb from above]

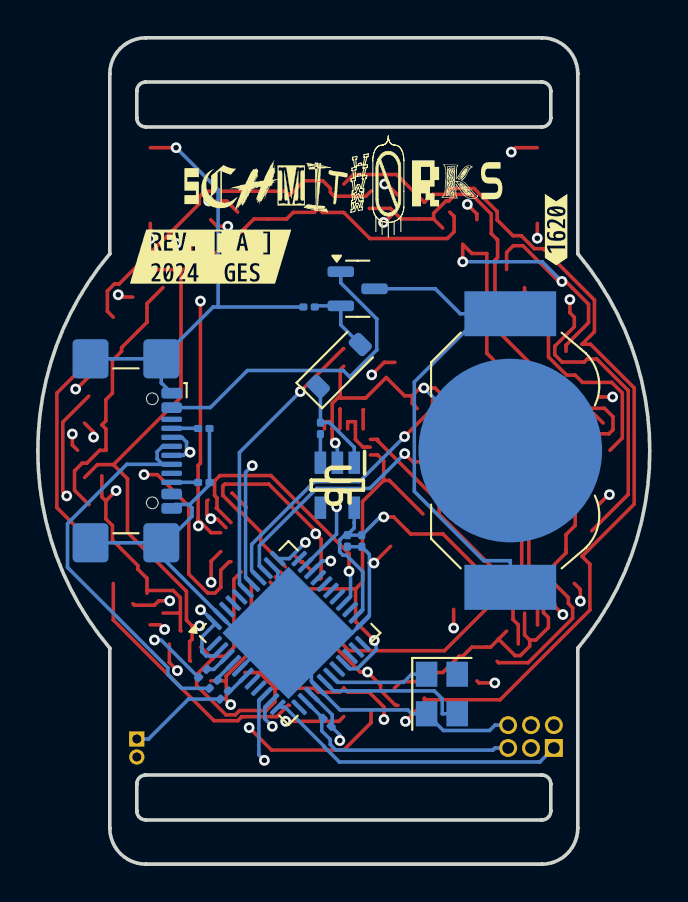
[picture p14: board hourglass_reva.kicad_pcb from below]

Board: 4 copper layers, 34.0 x 45.9 mm, 97 parts (19 on the bottom side), 42 nets.

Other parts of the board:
kibuzzard-66A6C66D: G***; kibuzzard-66A6C66D
kibuzzard-66A6C661: G***; kibuzzard-66A6C661
kibuzzard-66A7D7EA: G***; kibuzzard-66A7D7EA
kibuzzard-66A7EADD: G***; kibuzzard-66A7EADD
